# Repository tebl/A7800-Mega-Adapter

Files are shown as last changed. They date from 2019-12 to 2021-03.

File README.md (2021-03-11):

# Atari 7800 Mega Adapter
Let's face it, the controllers that came with the Atari 7800 are truly painful to use... unfortunately, both of the variants for the system suffer from the same problem (just for different reasons)! This may go a long way to explain why I've spent somewhere around an hour total playing on the system despite owning it for a few years, so I thought it was about time I did something about it. The easiest option is to just use a single-button joystick, but then I'd lose out on the features the second button provides so I decided to just use a different controller instead; the Sega Mega Drive / Genesis controller.

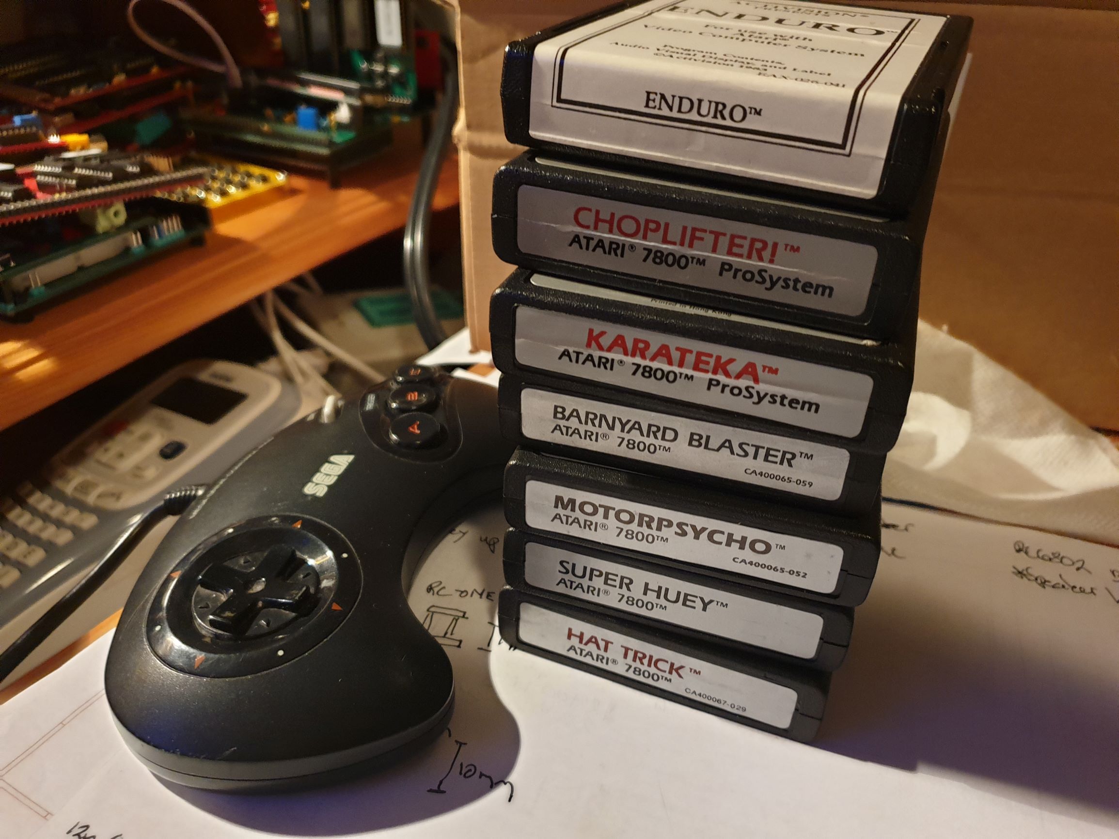
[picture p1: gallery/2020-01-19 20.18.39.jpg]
Atari + Sega


I based this project on the FAQ over at AtariAge.com, so if the design looks like something you've seen before then that's probably the reason why. I've built it up and tested it on my Atari 7800 PAL system, seems to work pretty good with the wired 3-button controller (don't have a 6-button variant to test out with). Unfortunately it doesn't seem to work with the new wireless 8bitdo controllers, but at least I finally get to test out some of the games without my hands aching and turning intolerable after 5-minutes of game time.

If you want an alternative to using a Sega Mega Drive controller, I've also created an [adapter](https://github.com/tebl/C64-JoyKEY/tree/main/adapters/Atari%207800) so that my [C64 JoyKEY](https://github.com/tebl/C64-JoyKEY)-controller can be used with the Atari 7800 system.

## Building the adapter
Mark Fixes Stuff on Youtube did a segment called [Making a Sega Megadrive Controller Adapter for Atari 7800! Full Build & Games Testing!](https://www.youtube.com/watch?v=7EVtcfSCWJM) that shows every part of assembling this adapter, particularly useful for those of us that are not used to soldering together new equipment from a bucket of parts. Keep reading from at more text-oriented description of the assembly process.

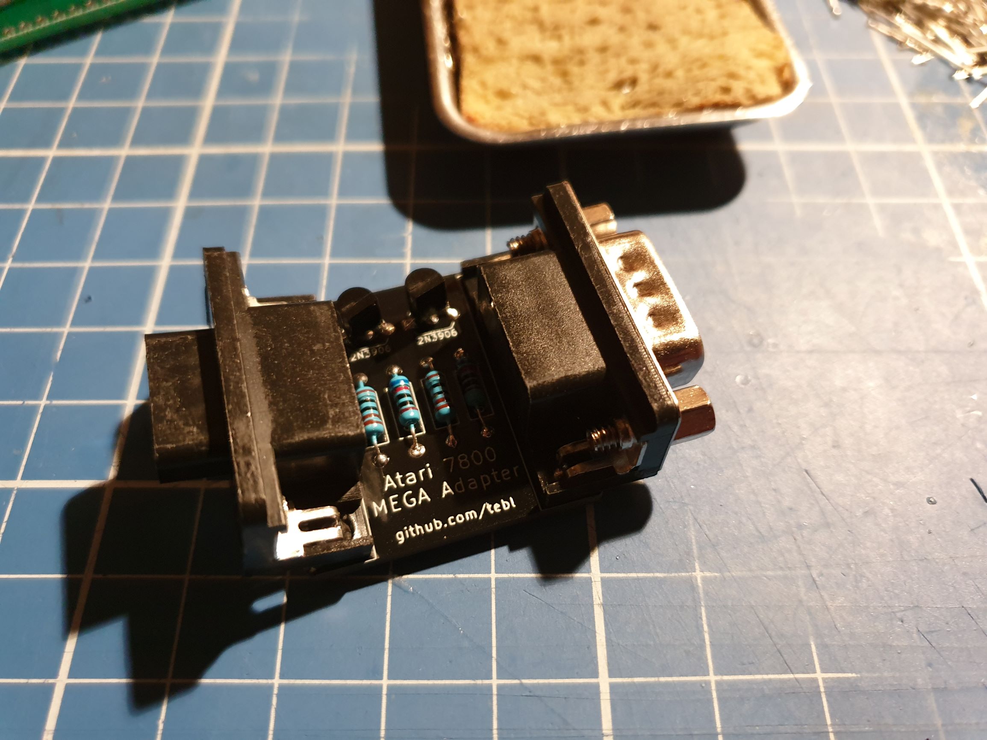
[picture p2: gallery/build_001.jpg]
Build 001


One thing to note, the main PCB of the Atari 7800 isn't actually mounted flat so the controller ports are actually angled quite a bit downwards! This means that the female DSUB-9 port that goes into the Atari 7800 will have to be soldered in place at an agle, preferably as far as you can take it and still be able to solder the pins into place.

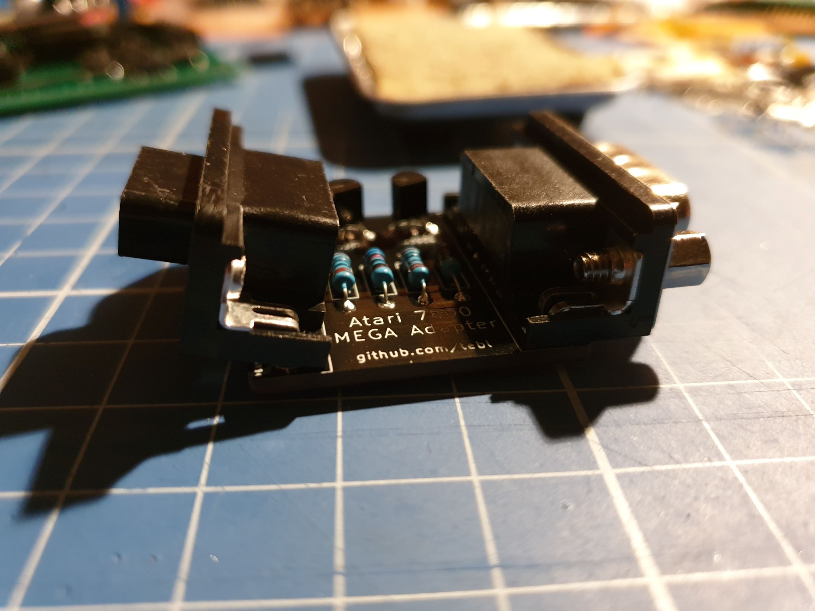
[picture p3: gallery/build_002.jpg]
Build 002

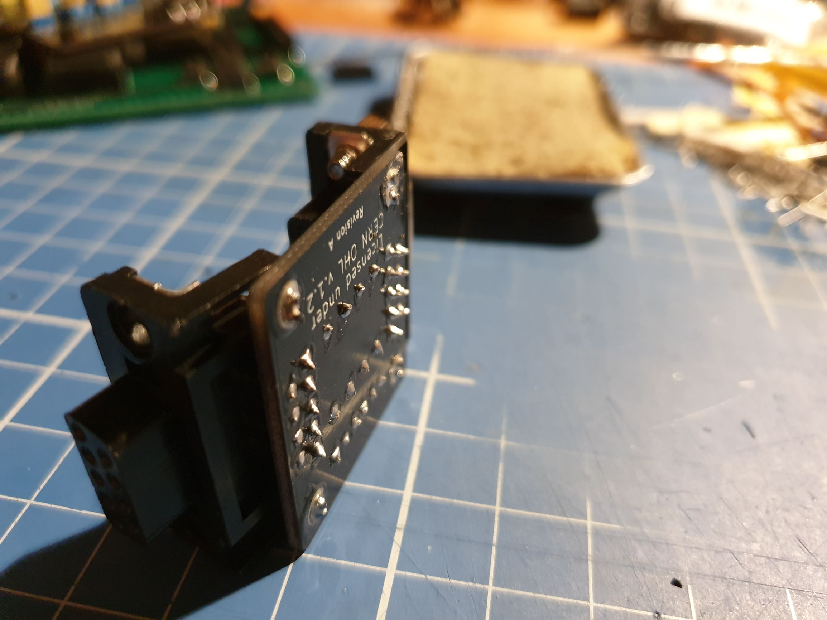
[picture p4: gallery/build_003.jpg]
Build 002


As can also be seen in the picture above, the metal shroud that comes mounted on the female DSUB-9 has been removed after soldering it into place. The male connectors on the Atari 7800 console is made out of plastic and not metal, so it no longer serves a purpose - the plastic on these have also grown brittle over the years, so reducing the strain on it will hopefully also keep it from splitting).

# Schematic
The supplied KiCad files should be sufficient as both a schematic and as a  starting point for ordering PCBs (basically you could just zip the contents of the export folder and upload that on a fabrication site), the schematic is also available in [PDF-format](https://github.com/tebl/A7800-Mega-Adapter/blob/master/export/A7800%20Mega%20Adapter.pdf) and this is what you'll need to print and work your way through this things don't work as expected after assembly.

# BOM
Most parts should be easy to get a hold of from your favourite local electronic component shop, but given that I don't have access to such shops where I live so everything was based on whatever I could get cheapest from eBay/AliExpress (free shipping, plan on waiting 3-4 weeks for delivery though).

| Reference | Item | Count | Order |
| --- | --- | ----- | ----- |
| PCB | Fabricate using Gerber files | 1 | [PCBway](https://www.pcbway.com/project/shareproject/Atari_7800_Mega_Drive_adapter.html) |
| J1 | Female DB9 right-angle connector | 1 | |
| J2 | Male DB9 right-angle connector | 1 | |
| Q1,Q2 | 2N3906 TO-92 transistor | 2 | |
| R1,R3 | 620 ohm resistor | 2 | |
| R2,R4 | 1k ohm resistor | 2 | |

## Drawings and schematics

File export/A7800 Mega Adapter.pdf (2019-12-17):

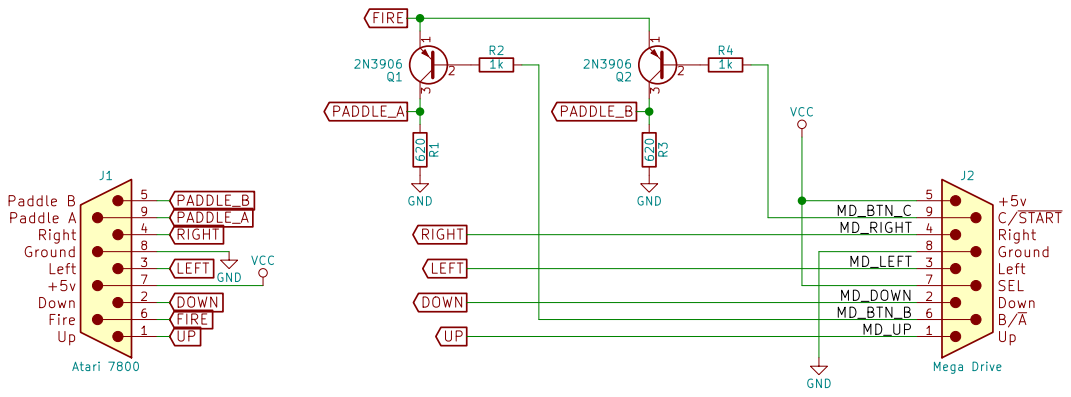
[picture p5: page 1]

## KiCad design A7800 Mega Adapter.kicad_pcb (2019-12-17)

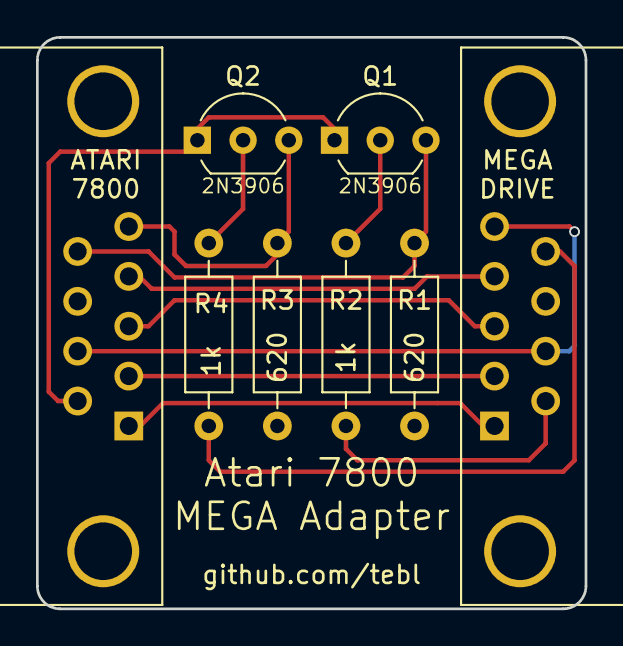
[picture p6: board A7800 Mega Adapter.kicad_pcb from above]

Board: 2 copper layers, 30.5 x 31.8 mm, 8 parts (0 on the bottom side), 13 nets.

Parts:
J1: Atari 7800; DSUB-9_Female_Horizontal_P2.77x2.84mm_EdgePinOffset7.70mm_H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
J2: Mega Drive; DSUB-9_Male_Horizontal_P2.77x2.84mm_EdgePinOffset7.70mm_Hou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
Q1, Q2: 2N3906; TO-92_Inline_Wide
R1, R3: 620; R_Axial_DIN0207_L6.3mm_D2.5mm_P10.16mm_Horizontal
R2, R4: 1k; R_Axial_DIN0207_L6.3mm_D2.5mm_P10.16mm_Horizontal

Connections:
/MD_BTN_B: J2.6, R2.2
/MD_BTN_C: J2.9, R4.2
DOWN: J1.2, J2.2
FIRE: J1.6, Q1.1, Q2.1
GND: J1.8, J2.8, R1.2, R3.2
LEFT: J1.3, J2.3
unnamed: Q1.2, R2.1
unnamed: Q2.2, R4.1
PADDLE_A: J1.9, Q1.3, R1.1
PADDLE_B: J1.5, Q2.3, R3.1
RIGHT: J1.4, J2.4
UP: J1.1, J2.1
VCC: J1.7, J2.5, J2.7

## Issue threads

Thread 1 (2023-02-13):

Can I substitute the 620 ohm resistors with 680 ohm ones instead?

RetroInVitro, 2023-02-13:
or would using a lower resistance value one like a 510 ohm be better (or less worse) than 680 ohm one?

thanks.

RetroInVitro, 2023-02-21:
Rephrasing:

the PCB calls for a 620 ohm resistor for R1 and R3.  If I don't have a 620 ohm resistor, is it better to use 510 or 680 ohm ones as substitutes?

i.e. is it better to have 60 ohms more resistance or 90 ohms less?

tebl, 2023-02-21:
I have not done the math on it, but it is a digital signal so I don't think
ot would matter much - parts from that era would have had as much variance
anyway. I would just try the slightly higher value.

tir. 21. feb. 2023, 04:19 skrev Retrogaming ***@***.***>:

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

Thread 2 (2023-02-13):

Can the adapter be used as a ColecoVision 2-button adapter?

RetroInVitro, 2023-02-13:
Since the OEM 7800 controller will work on a ColecoVision for two button games, will this adapter allow Genesis / Megadrive controllers to work on the CV as it does for the A7800?

tebl, 2023-02-13:
Going by the pinouts that I could fine for wiring up one, I'd consider it
in the category of accidentally working if it did work. I think I would
look for something directly for the Colecovision.

https://cvaddict.com/article.php?articleid=16

man. 13. feb. 2023, 19:26 skrev Retrogaming ***@***.***>:

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

RetroInVitro, 2023-02-13:
Thank you.  I appreciate the guidance.   Do you have insight into how the OEM 7800 controllers work on the CV?

tebl, 2023-02-14:
I don't know how they would specifically work as I've never seen a
Colecovision, but I suspect the reason the OEM controllers work is that
they've been directly wired to match the competitors product. When adding
an adapter and something like a Genesis-controller into the mix, you've
added active circuitry that has its own requirements in order to work
reliably.

man. 13. feb. 2023 kl. 20:40 skrev Retrogaming ***@***.***>:

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

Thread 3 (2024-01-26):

All the buttons on my mega model 1850 pad don't work

grzegorzzyla, 2024-01-26:
I have 3 buttons A B C and START. Only 1 button works via the adapter. Interestingly, when I connect the quickshoot python joystick and set it to the SEGA standard, both buttons on the joystick work.
I looked at the controller diagram https://www.raspberryfield.life/2019/02/15/sega-mega-drive-genesis-3-button-abc-controller/ I have exactly the same model, only there is a different PCB, the direction contacts are on the same side as the buttons.
What is wrong?

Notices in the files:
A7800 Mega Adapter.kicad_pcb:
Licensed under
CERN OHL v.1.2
